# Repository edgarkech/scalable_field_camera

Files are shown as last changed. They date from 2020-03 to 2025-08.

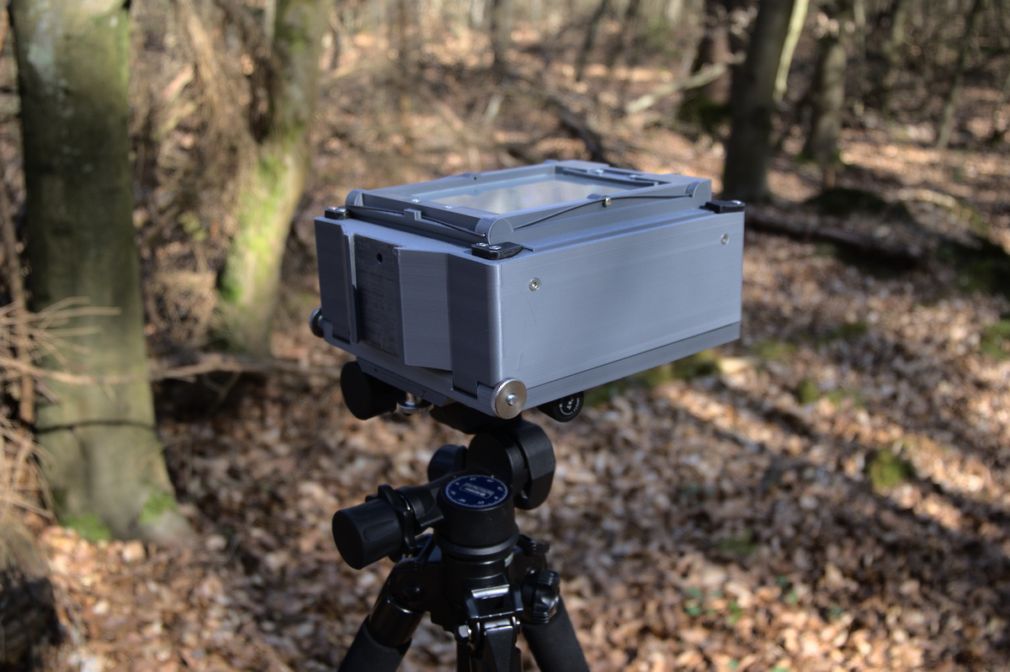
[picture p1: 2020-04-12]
pictures/version_1.0/XT203503.jpg

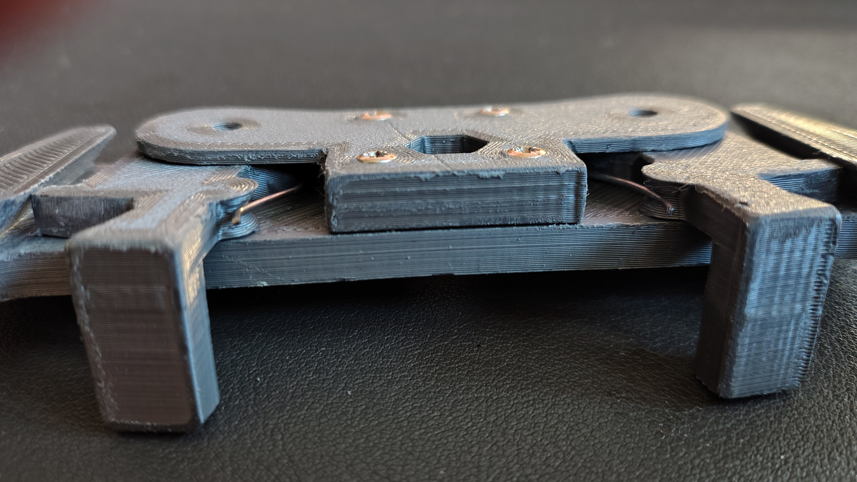
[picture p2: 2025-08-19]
pictures/version_1.0/IMG_20250819_194543976_HDR.jpg

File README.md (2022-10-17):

# Scalable large format field camera - 4&times;5 - 5&times;7 - 8&times;10

_This is my attempt to create a scalable large format field camera design._

## Project goals:
- of course a 3d printable and usable large format field camera in 4x5" format. The design should be scalable to 5x7" or even 8x10" by just changing a handful of variables.
- Learning OpenSCAD. Learning to use it efficiently. Learning to do good parametric development/design.
- Learning git/github and sharing my code with other people
- Checking out the limits of home 3D printing with a very limited set of available tools

## Some technical goals:
- the design is inspired by old and established field cameras like Horseman 45HD/FA or Linhof Technika. But it is also inspired by Intrepid and Standard Camera
- compact and lightweight. Projected weight for the 4x5 version with ground glass but without lens is below 1500g. The "overall package" should be lightweight, so don't expect me to design a rail and front standard for holding big and heavy lenses. for 4x5": usable with lenses from 90-300mm. Shorter or longer lenses are not targeted.
- a small standard lens should be able to stay on the camera when it is closed (e.g. Fujinon-WS 150/6.3 or Symmar 135/5.6, ...)
- rise of about 25-30mm with a normal lens
- fall of about 10mm with a normal lens
- front/back tilt of about 10 degrees
- left/right swing of about 10 degrees
- left/right shift optionally (probably not with first release)
- all movements on the front standard, no movements on the back
- easy switchable from landscape to portrait format
- tripod mount with Arca Swiss type mount
- all parts must be either 3D-printable or easily available.
- no special tools required besides a decent 3D printer and some common tools like little files, screwdrivers, sanding paper, cutter, scissors, ...
- no exotic third party parts/components
- form follows function
- KISS

## Early design decisions:
- completely 3D printed rail and front standard mechanism - lots of dovetails :-)
- for the initial 4x5 version I will use a bellows from standard cameras (https://www.standardcameras.com/product/replacement-bellows-v1-0/). For now it's relatively easy available, cheap and already mounted into a frame. For later versions, I will probably switch over to another source and add my own bellows mounting frame. For working with alternative bellows see the hints in the README file in folder STL_4x5, since you will have to build customized bellows frames using SCAD files.
- for the 5x7 version I will use a bellows from ebay-shop "ecbuyonline2008" which is orginally for a Linhof Technika 5x7 IV or V
- for the focusing rod I will use 6mm rods with 2mm pitch
- due to some printing related problems (first layer), I will avoid printing small holes directly onto the printing bed (smaller than 5mm). If holes are required, they will have a little offset on the Z-axis of 0.5mm. This will allow a "clean" first layer with really good adhesion, while the holes are "pre-drilled" for most of their depth

## First findings after finishing the first functional prototype
- PETG printing is somehow okay, but PLA is more rigid. Although I will do further tests with PETG, PLA stays the preferred material. This applies especially to the dovetails.
- completely printed front standard with (more than) acceptable stability is possible
- overall design seems to be a good starting point for further optimizations

## to do / next steps
- more real world testing (first tests successful)
- work around the current -7/+7 degrees tilt restriction (low priority)
- mechanism to lock the front lid when folding (done)
- foldable hood for the ground glass
- OpenSCAD code clean up and refinement (done)
- releasing the OpenSCAD code and make this project real open source  (done)
- scaling up to 5x7" (done)
- re-evaluate 4x5" bellows options (different source, design for configurable bellows frames is done) 
- using the built-in github wiki for documentation

# Update 2020-05-23
The 5x7 version is also finished. Although the 5x7" version is technically identical to the 4x5", there have been some changes to all SCAD files and I didn't test all of them again with 4x5. 
So if you are brave enough to work with the SCAD files to generate your own (4x5") STLs, please check them against my original 4x5 STLs.

# Update 2022-10-17
In the past there were some rumours or jokes about creating the 8x10" version, but nobody seemed to be brave enough to start the upscaling project. Or maybe the initially brave people gave up in despair... 
Until today. I had a conversation with Miguel Mesa (https://www.facebook.com/miguemesa), who now wants to start scaling up the design to 8x10" - which would be another milestone for my design. 
Although I am still pausing most of my photographic and 3d printing related activities, I am really curious how my design may evolve. And I want to encourage all watchers interested in a 8x10" version to participate and maybe even contribute to this next milestone.   

**Some very kind people asked me about the possibility to show their appreciation by donating to me.**

If you really felt somehow obliged to do so, then you should use https://paypal.me/EdgarKech :-) .
But I am also happy if you post pictures of your build to https://www.facebook.com/groups/3dprinting.and.analog.photography/

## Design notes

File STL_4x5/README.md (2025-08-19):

# 4&times;5 parts list

**We put our format specific STL files in here, so we get a complete set of STL files for building a camera in the specified format**

## Printed parts

All parts can be printed on any decent 3D printer with sufficient build volume 
- for 4x5" a smaller printer with about 190x190x100mm build volume is sufficient

Print settings vary slightly for the different parts - if not explicitly mentioned use
- 0.2mm layers or better
- 4 walls
- 4 bottom/top layers
- when printing with PETG, use at least 15-20% more infill as hinted below, below numbers are for PLA
The tolerances between the parts are quite tight, so you have to sand them. I recommend sanding the dovetail parts with 400 wet sanding paper. 

### printed parts list
- body, infill 30%, support for overhang angles over 60 degrees, support touching the build plate
- front lid, infill 30%, no supports
- front lid dovetail, infill 30%, no supports
- focusing block, infill 100%, no supports
- focusing wheel, infill 100%, no supports
- back plate, 30% infill, no supports
- locking rails (1x original, 1x mirrored), infill 100%, no supports
- locking levers (1x original, 1x mirrored), infill 100%, no supports
- rails, min 40% infill, support for overhang angles over 60 degrees
- slider, min 50% infill, no supports
- front standard, min 50% infill, support for overhang angles over 80 degrees, support everywhere, do not print the standard in its upright position, but layed down to its back side
- front standard tilt plates (2x) min 50% infill, support for overhang angles over 80 degrees, support touching the build plate
- pulling lever plate, 100% infill, no supports
- pulling levers (1x original, 1x mirrored), 100% infill, no supports
- lensboard carrier, min 40% infill, support for overhang angles over 60 degrees, support touching the build plate
- lensboard lower clamp, 100% infill, no supports
- lensboard upper clamp, 100% infill, no supports
- ground glass frame, infill 30%, no supports,
- ground glass clamps, 100% infill, no supports
- tripod plate, min 50% infill, no supports
- only needed when not using a bellows from standard cameras: bellows front frame, min 50% infill, no supports
- only needed when not using a bellows from standard cameras: bellows back frame, min 50% infill, no supports

### non-printed parts
- bellows, for 4x5" order the bellows from standardcameras.com or from eBay or from aliexpress (e.g. from ecbuyonline2008 aka eTone)
- focusing rod: T6, 2 or 4mm lead, 160mm length
- T6 nut (brass) 
- flange coupler 6mm
- M5 threaded rod, 200mm
- M5x20 screw (1x)
- M5x10 knurled nuts (3x)
- M5x10...12 screws with knurled heads (2x)
- M5x12...16 screws with knurled heads (2x)
- M5 press-in nuts (5x)
- countersunk screws 3x12 (about 35x)
- countersunk screws 2x10 (about 10x)
- ground glass 127x101mm
- about 600mm of 1.25mm spring steel wire for the ground glass frame
- about 100mm of 0.75mm spring steel wire for the pulling lever mechanism

## some hints & sources:
### bellows
History has shown that standardcameras is sometimes out of stock for the bellows.
- Alternative 1: build your own bellows (sorry, no howto from me, but there are lots of excellent sources!)
- Alternative 2: Find a replacement bellows for another field camera (e.g. Linhof Technika 4x5, Toyo 45A, Horseman, HD/HF/FA 45, ...). 

Make sure to get squared bellows with a front measurement of something between 88 and 98mm (default is 94mm) and a back measurement of something between 141 and 153mm (default is 144mm).

You have to create your own STLs for the bellow frames from the according SCAD files. In the config_4x5.scad file find the variables "vBellowsFrontInner_l" and "vBellowsBackInner_l" and change them to the measurements of your bellows - don't change anything else unless you have a really good reason for it. Let OpenSCAD render your SCAD files and export to STL.

### bellows frames (in case you are not using bellows from standard cameras):
The bellows frames consist of two individual parts (inner and outer frame), but I modeled them as one piece for easier modeling and printing. 
They are just "linked" together via the bottom 0.1mm (for easier printing). Just use a knife to split inner and outer frame and clean up the edges.

### dove tails:
the fit of the various dove tails may be very tight in the beginning. So I'd recommend pre-assembling the dovetails and trying to move the parts. If it is too tight, use fine sandpaper until there is only very little friction. It shouldn't get wobbly.

### front standart:
don't try to print the front standart in its upright position. Lay it down ot its back side and make sure to allow support everywhere.
Assembling:
- Make sure the dove tails of slider and front standard aren't too tight (see section "dove tails")
- put slider and front standard together before assembling the pulling lever mechanism.

### pulling levers assembly
- pulling levers and pulling lever plate: put them together and rotate the pulling levers on their axis until there is no noticable friction. If the holes in the levers are too small, use a 8mm drill bit (just by hand) to widen it.
- pulling lever plate: make sure that little horizontal hole is open (if not, you could use either a 1.5mm drill bit or a hot wire to push it open). This is where you put the spring wire through and bend it on both sides almost to a right angle (let's say 110 degrees). Don't cut the spring steel wire too short before final assembly.
- see the pictures in the pictures/version_1.0 folder https://github.com/edgarkech/scalable_field_camera/tree/master/pictures/version_1.0 

### assembling the front standard
- start with slider and front standard, otherwise it may be difficult to get the front standard onto the slider with the pulling levers already assembled.
- pre-assemble pulling lever plate, spring wire and pulling levers
- put the pulling assembly to the bottom of the slider and screw it to the slider.
- see again the pictures in the pictures/version_1.0 folder https://github.com/edgarkech/scalable_field_camera/tree/master/pictures/version_1.0 

### focusing rod:
Find "T6 lead screw" with fitting brass nuts on aliexpress, ebay or your preferred source, similar to this offer: https://www.aliexpress.com/item/32507277503.html. 
Take either 2mm or 4mm lead with 200mm length. 
Cut it to about 160 to 165mm. 
Press the nut into the 10mm hole of the rail lever. 
Secure it with one small screw and file down everything hanging over
- see again the pictures in the pictures/version_1.0 folder https://github.com/edgarkech/scalable_field_camera/tree/master/pictures/version_1.0 

### focusing wheel:
Find "6mm flange coupler" on aliexpress, ebay or your preferred source, similar to this offer: https://www.aliexpress.com/item/4000208248034.html.
Press it into the Focusing wheel and align the side holes with the threads, so you can screw in the tiny screws.

### threaded inserts:
Find "M5 threaded insert" on aliexpress, ebay or your preferred source. I am using M5x6x7 brass insert similar to this: https://www.ebay.com/itm/M5x-5-16mm-Injection-Molding-Nut-Brass-Knurled-Thread-Inserts-Nuts/332250787457. 
Make them hot and press them into the according holes using a M5 threaded rod or a longer screw.

### knobs:
All knobs are quite standard M5 screws or nuts. 
3x nut M5, one for swing and two for the lid. 
2x M5x16 for tilt, 2x M5x12 for shift (the flat ones). 
Also one M5x12 for the tripod plate. 
I prefer stainless steel but anything else with similar size will do.

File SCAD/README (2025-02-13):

Some hints about the scripting and according conventions in here - as my OpenSCAD scripting is learning by doing, some constructs may look crude or even violate best practice.
I am using some rules and conventions to make my scripting as consistent, readable and maintainable as possible.

General logic for getting this design parametric:
- baseconfig.scad holds very generic configuration values which are independent of the targeted camera format. But it also includes the format specific config file.
- config_4x5.scad/config_5x7.scad/config_8x10.scad are the format specific configuration files. Here we set some basic, format specific variables from which we can derive lots of measures for our design
- all other scad files are including the baseconfig.scad file to get all basic and format dependent variables for deriving the specific measures

Naming conventions
- all Variables are prefixed with "v"
- all Variables are (somehow) speaking, eg. vFrontLidOuter_l
- suffix _l is typically a measure in x direction
- suffix _w is typically a measure in y direction
- suffix _h is typically a measure in z direction
- suffix _d/_d1/_d2 are typically a diameter variables
- suffix _r/_r1/_r2 are typically radius variables 
- suffix _offsetX/_offsetY/_offsetZ are offset variables to be used in translate() statements
- every basic element has its own set of l/w/h/d/r variables
- every element will have its own set of offset variables

Other conventions
- mathematic operations are done within the variables. 
- most parts are symetric, so we center them on the X axis
- try to keep the scripting readable

Creating STLs for bellows frames:
1. go to https://github.com/edgarkech/scalable_field_camera/releases/tag/v1.02 and download the complete source code zip-file. (skip, if your already downloaded+extracted the sources)
2. extract the zip file. you should find a subfolder "SCAD" (skip, if your already downloaded+extracted the sources)
3. go to the SCAD folder and open the "baseconfig.scad" file
4. make sure the correct format-specific include line is active (not startingwith "//") - there are three lines, one for 4x5, one for 5x7, one for 8x10; the two lines NOT for your targeted format should be commented out, e.g. starting with "//"
5. if necessary make changes by commenting/uncommenting and save the file
6. open the relevant format-specific config file (probably config_4x5.scad)
7. take the real measurements from your bellows. On the front you should have a measurement somewhere between 88 and 98mm (default is 94), on the back it should be between 141 and 153mm (default is 144mm)
8. find the variables "vBellowsFrontInner_l" and "vBellowsBackInner_l" and change them to the measurements of your bellows - don't change anything else unless you have a really good reason for it. 
9. save the file.
10. open the bellows_front_frame.scad file, let OpenSCAD render it and export to STL.
11. open the bellows_back_frame.scad file, let OpenSCAD render it and export to STL.
12. print your STL files

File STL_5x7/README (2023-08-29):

We put our format specific STL files in here, so we get a complete set of STL files for building a camera in the specified format

Printed parts

All parts can be printed on any decent 3D printer with sufficient build volume 
- for 5x7" a build volume of at least 235x235x100mm is required

Print settings vary slightly for the different parts - if not explicitly mentioned use
- 0.2mm layers or better
- 4 walls
- 4 bottom/top layers
- when printing with PETG, use at least 15-20% more infill as hinted below, below numbers are for PLA
The tolerances between the parts are quite tight, so you have to sand them. I recommend sanding the dovetail parts with 400 wet sanding paper. 

printed parts list
- body, infill 30%, support for overhang angles over 60 degrees, support touching the build plate
- front lid, infill 30%, no supports
- front lid dovetail, infill 30%, no supports
- focusing block, infill 100%, no supports
- focusing wheel, infill 100%, no supports
- back plate, 30% infill, no supports
- locking rails (1x original, 1x mirrored), infill 100%, no supports
- locking levers (1x original, 1x mirrored), infill 100%, no supports
- rails, min 40% infill, support for overhang angles over 60 degrees
- slider, min 50% infill, no supports
- front standard, min 50% infill, support for overhang angles over 80 degrees, support everywhere, do not print the standard in its upright position, but layed down to its back side
- front standard tilt plates (2x) min 50% infill, support for overhang angles over 80 degrees, support touching the build plate
- pulling lever plate, 100% infill, no supports
- pulling levers (1x original, 1x mirrored), 100% infill, no supports
- lensboard carrier, min 40% infill, support for overhang angles over 60 degrees, support touching the build plate
- lensboard lower clamp, 100% infill, no supports
- lensboard upper clamp, 100% infill, no supports
- ground glass frame, infill 30%, no supports,
- ground glass clamps, 100% infill, no supports
- tripod plate, min 50% infill, no supports
- bellows front frame, min 50% infill, no supports
- bellows back frame, min 50% infill, no supports

non-printed parts
- bellows, order the bellows from from eBay or aliexpress
- focusing rod: T6, 2 or 4mm lead, 200mm length
- T6 nut (brass) 
- flange coupler 6mm
- M5 threaded rod, 250mm
- M5x20 screw (1x)
- M5 knurled nuts (3x)
- M5x10 screws with knurled heads (2x)
- M5x12 screws with knurled heads (2x)
- M5 press-in nuts (4x)
- countersunk screws 3x12 (30x)
- countersunk screws 2x10 (6x)
- ground glass 5x7"
- about 700mm of 1.25mm spring steel wire for the ground glass frame
- about 100mm of 0.75mm spring steel wire for the pulling lever mechanism

some hints & sources:
focusing rod:
Find "T6 lead screw" with fitting brass nuts on aliexpress, ebay or your preferred source, similar to this offer: https://www.aliexpress.com/item/32507277503.html. 
Take either 2mm or 4mm lead with 200mm length. 
Cut it down to fit into the lid. 
Press the nut into the 10mm hole of the rail lever. 
Secure it with one small screw and file down everything hanging over

bellows frames:
The bellows frames consist of two individual parts (inner and outer frame), but I modeled them as one piece for easier modeling and printing. 
They are just "linked" together via the bottom 0.1mm (for easier printing). Just use a knife to split inner and outer frame and clean up the edges.

front standart:
don't try to print the front standart in its upright position. Lay it down ot its back side and make sure to allow support everywhere.

focusing wheel:
Find "6mm flange coupler" on aliexpress, ebay or your preferred source, similar to this offer: https://www.aliexpress.com/item/4000208248034.html.
Press it into the Focusing wheel and align the side holes with the threads, so you can screw in the tiny screws.

threaded inserts:
Find "M5 threaded insert" on aliexpress, ebay or your preferred source. I am using M5x6x7 brass insert similar to this: https://www.ebay.com/itm/M5x-5-16mm-Injection-Molding-Nut-Brass-Knurled-Thread-Inserts-Nuts/332250787457. 
Make them hot and press them into the according holes using a M5 threaded rod or a longer screw.

knobs:
All knobs are quite standard M5 screws or nuts. 
3x nut M5, one for swing and two for the lid. 
2x M5x16 for tilt, 2x M5x12 for shift (the flat ones). 
Also one M5x12 for the tripod plate. 
I prefer stainless steel but anything else with similar size will do.

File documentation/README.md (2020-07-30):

# Documentation

Here's an attempt at guiding the assembly and build process of the Scalable Field Camera.

For now, it only contains an exploded view and assembly mockups in `assembly` but we aim to create a step-by-step guide soon :)

**The assembly images are based on the 4&times;5 camera files**

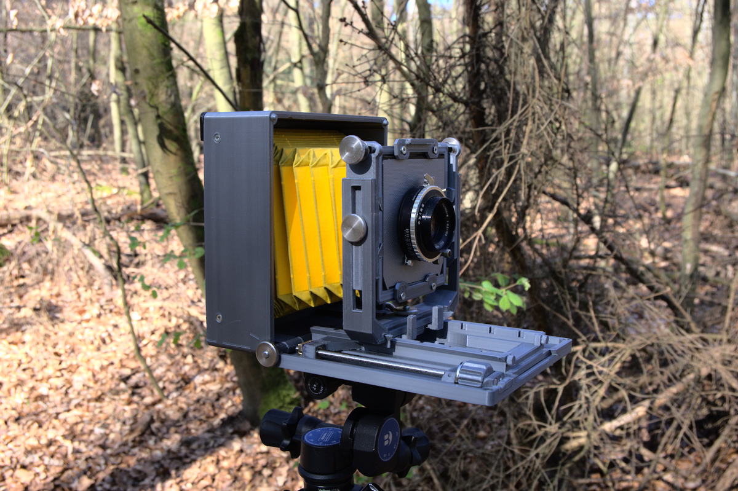
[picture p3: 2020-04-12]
pictures/version_1.0/XT203507.jpg

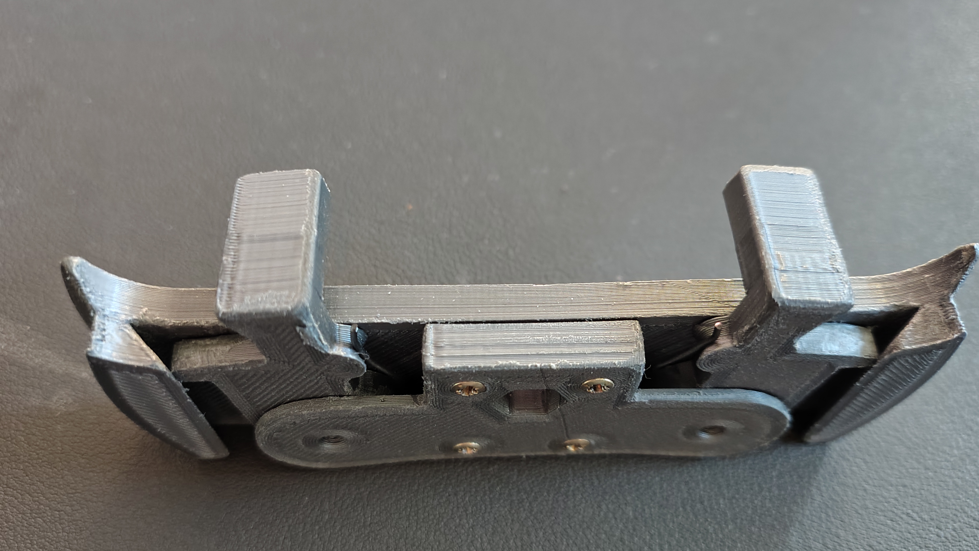
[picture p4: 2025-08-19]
pictures/version_1.0/IMG_20250819_194521298_HDR.jpg

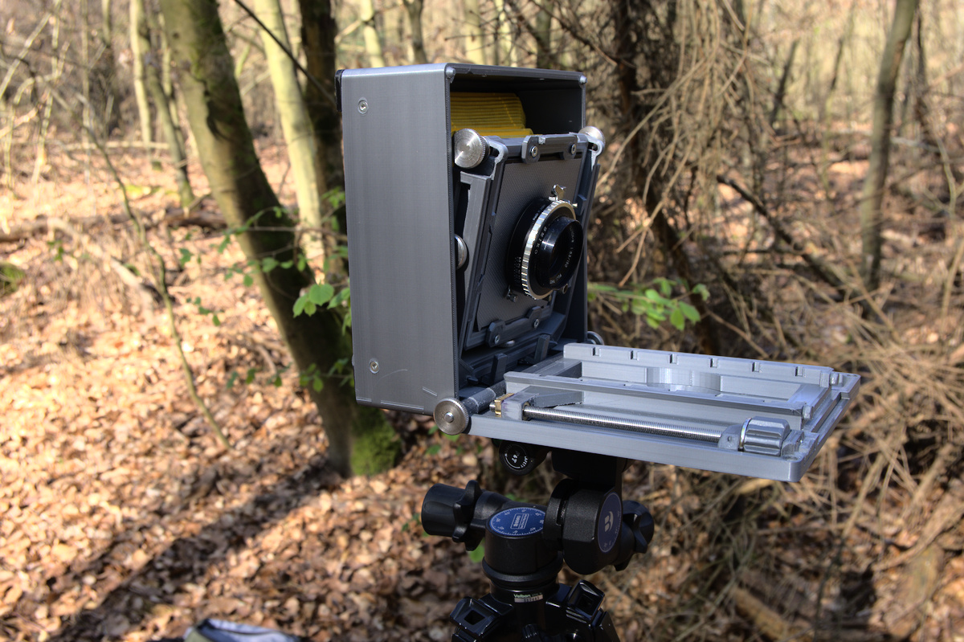
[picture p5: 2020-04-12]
pictures/version_1.0/XT203506.jpg

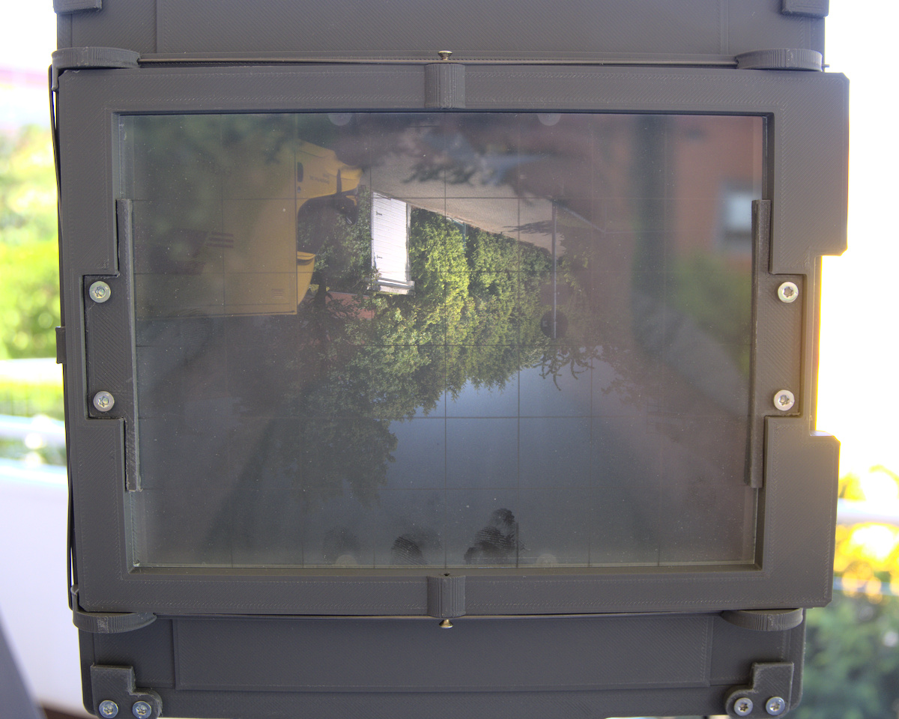
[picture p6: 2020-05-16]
pictures/XT203548.jpg

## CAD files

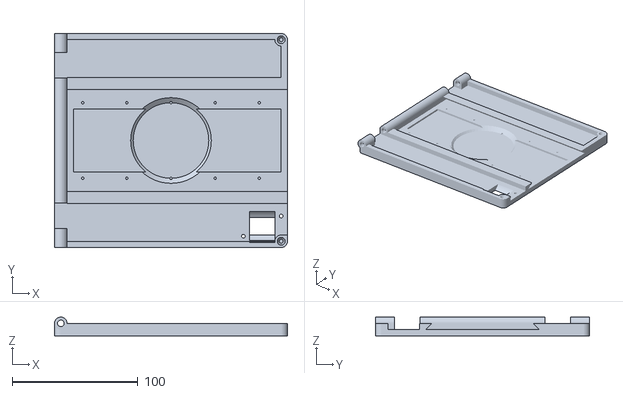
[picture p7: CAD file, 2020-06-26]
STL_4x5/front_lid.stl
185.0 x 170.0 x 15.0

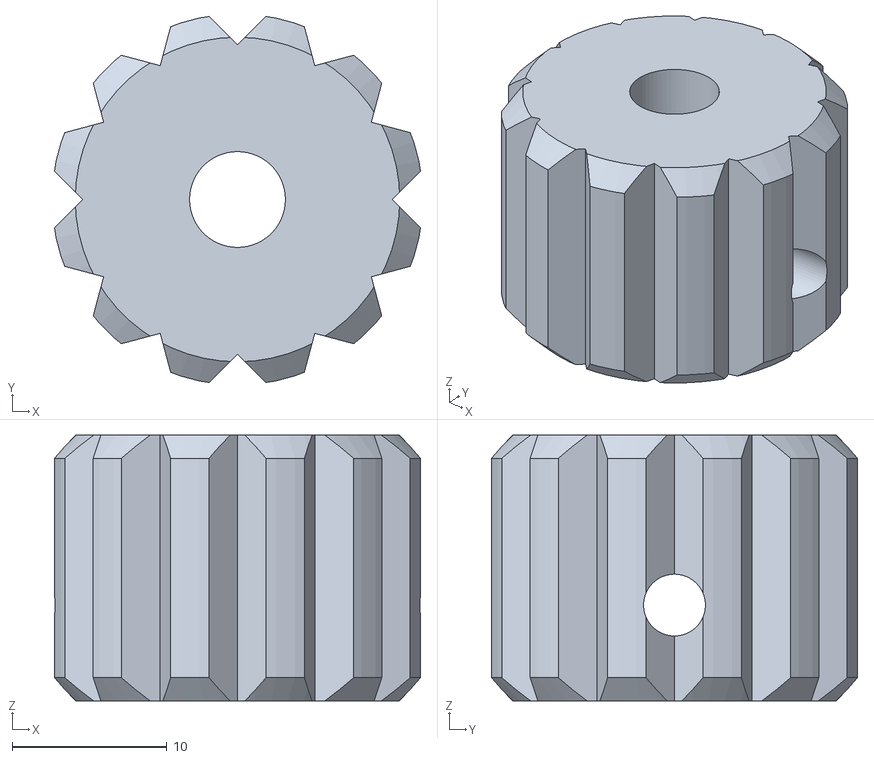
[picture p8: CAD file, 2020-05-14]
STL_5x7/focus_wheel.stl
23.7 x 23.7 x 17.2

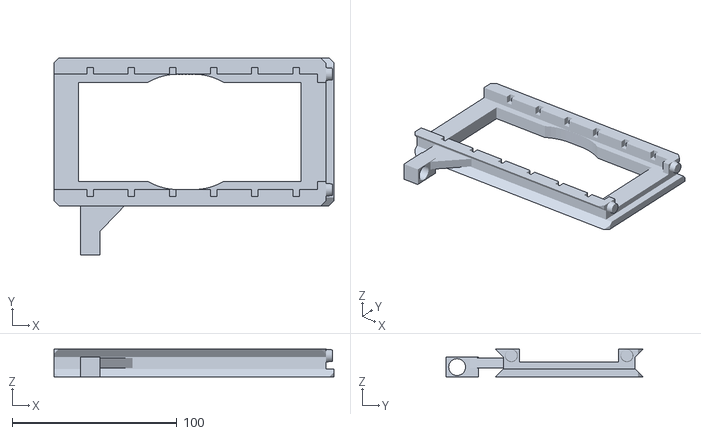
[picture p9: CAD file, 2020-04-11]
STL_4x5/rails.stl
170.0 x 119.7 x 17.0

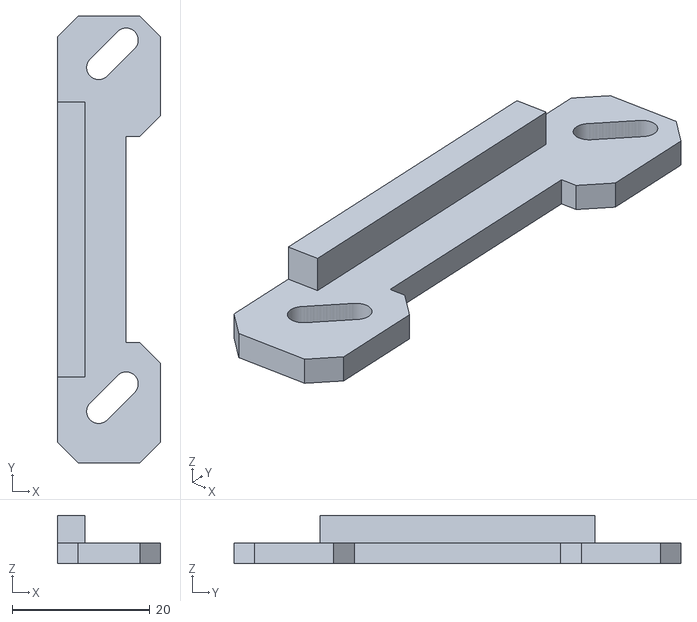
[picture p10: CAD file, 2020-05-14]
STL_5x7/lensboard_upper_clamp.stl
15.0 x 65.0 x 7.00

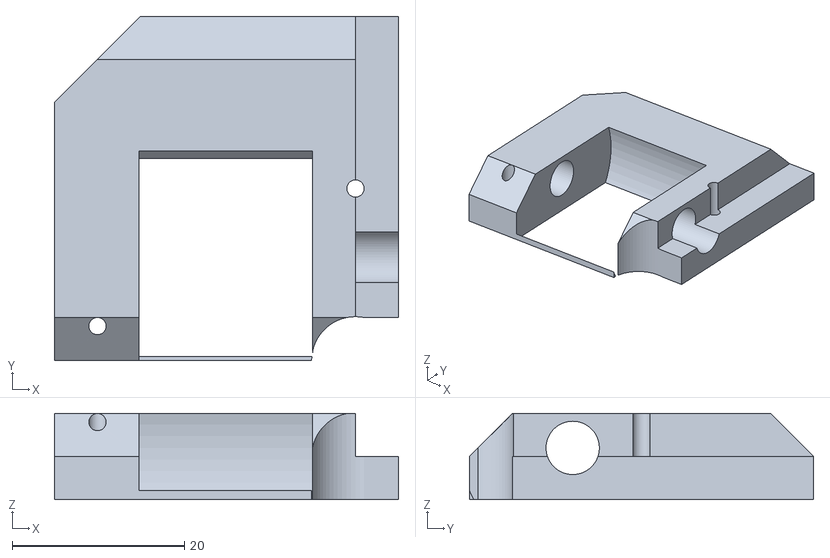
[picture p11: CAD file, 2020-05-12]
STL_5x7/focusing_block.stl
40.0 x 40.0 x 10.0

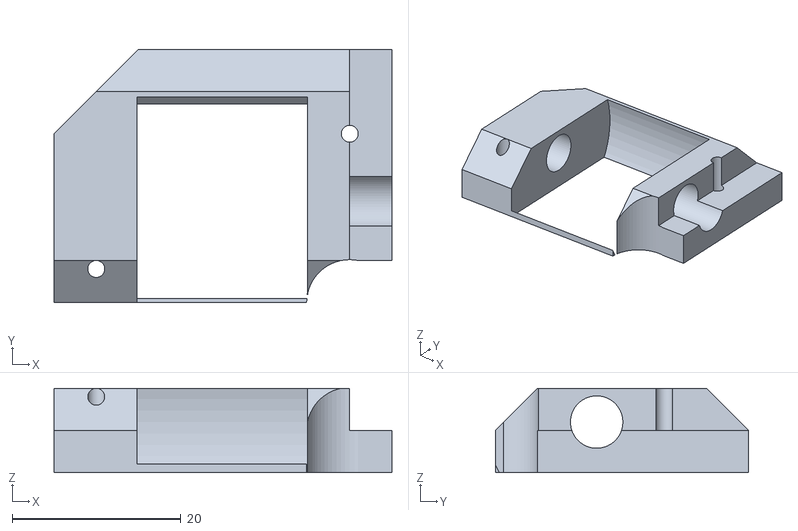
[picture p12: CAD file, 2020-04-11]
STL_4x5/focusing_block.stl
40.0 x 30.0 x 10.0

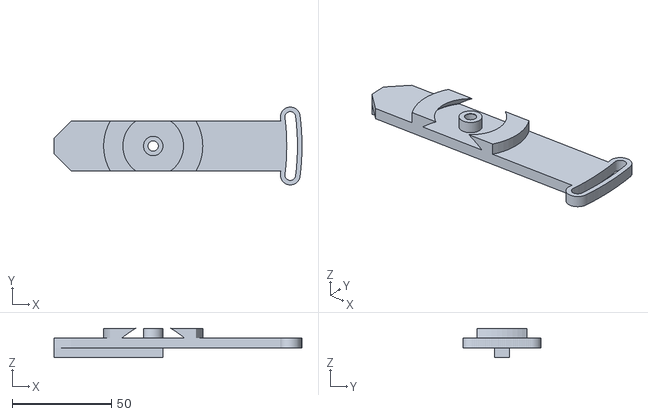
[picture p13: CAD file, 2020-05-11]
STL_5x7/front_standard_tilt_plate.stl
125.0 x 39.2 x 14.8

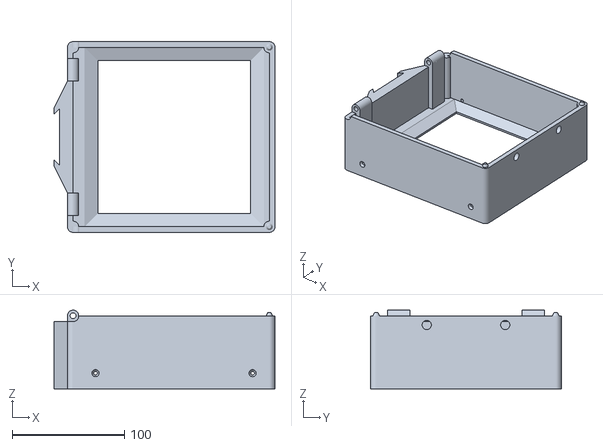
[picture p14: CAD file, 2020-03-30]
STL_4x5/body.stl
197.0 x 170.0 x 70.2

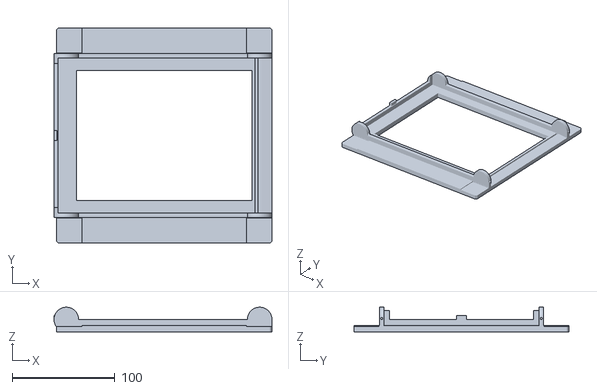
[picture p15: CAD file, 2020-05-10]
STL_5x7/back_plate.stl
212.1 x 209.6 x 24.0

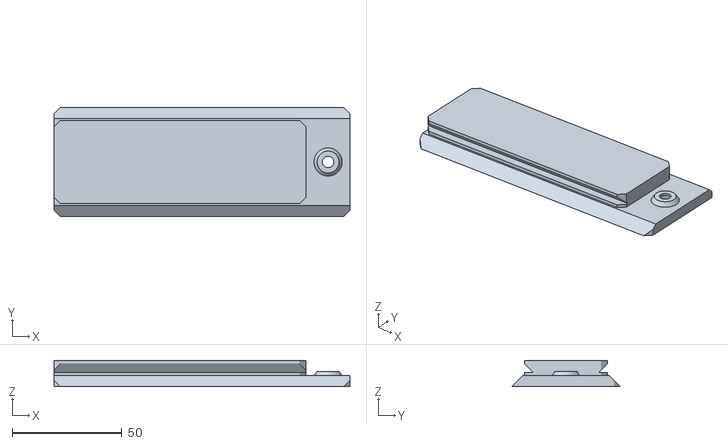
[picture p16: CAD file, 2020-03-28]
STL_4x5/tripod_plate.stl
135.0 x 49.8 x 12.0

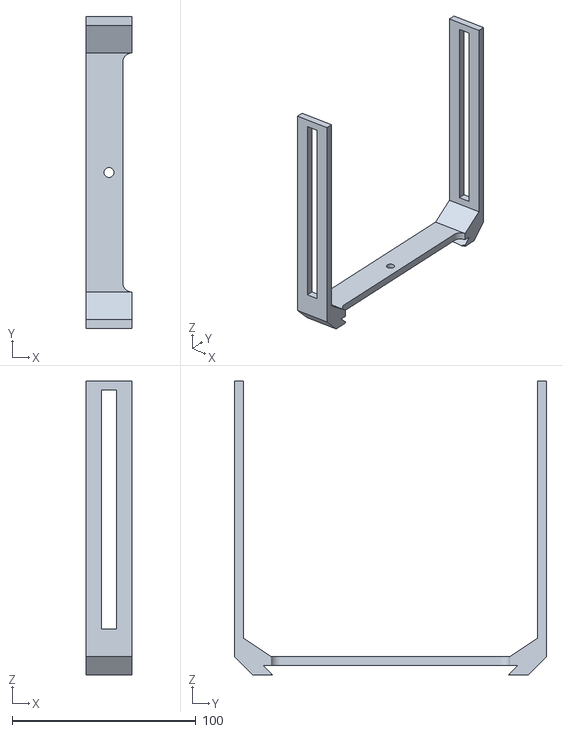
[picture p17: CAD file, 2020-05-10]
STL_5x7/front_standard.stl
25.0 x 170.0 x 160.0

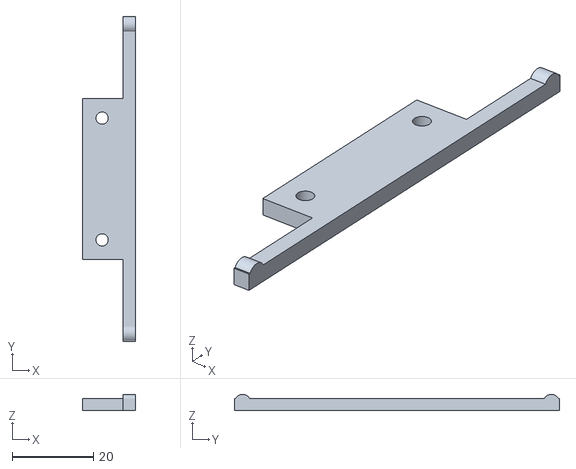
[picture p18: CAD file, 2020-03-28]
STL_4x5/ground_glass_clamp.stl
13.0 x 80.0 x 4.00

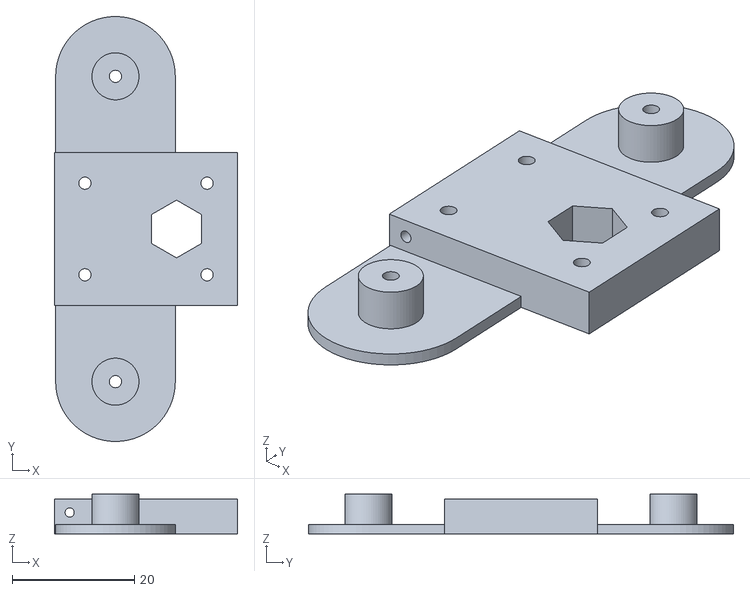
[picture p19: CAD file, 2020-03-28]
STL_4x5/pulling_lever_plate.stl
30.0 x 69.6 x 6.50

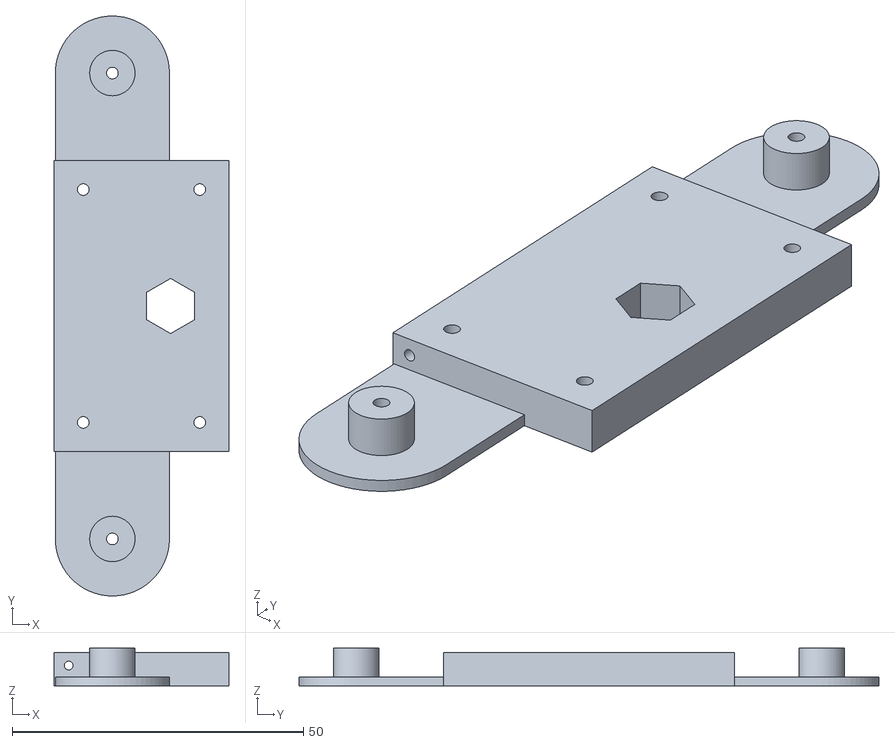
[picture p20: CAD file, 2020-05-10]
STL_5x7/pulling_lever_plate.stl
30.0 x 99.6 x 6.50

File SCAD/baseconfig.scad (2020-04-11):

/*
Here we define some variables which are independent from the camera format
*/


// some generic variables
$fn = 60; // we are using 60 fragments for cylinders and similar objects

// we are including a format specific configuration sheet - but make sure to include only one!

include <config_4x5.scad>;
// include <config_5x7.scad>;
// include <config_8x10.scad>;

// Arca Swiss tripod plate
// caution: some Arca Swiss compatible tripod heads may have slight variations
// vArca_length = xx; // the length is irrelevant here
vArca_width = 38;
vArca_height = 7;
vArcaBase_cutout = 4;
vArcaBase_height = 1.5;

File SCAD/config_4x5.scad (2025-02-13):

/*
This is the base configuration file for the 4x5" format
# we are not using the exact ANSI measures, but slightly rounded measures for slight simplification
*/

// general tolerance
vTolerance = 0.2;

// sheet film and cassette measurements (roughly based on the ANSI measurements)
vFilmSheet_l = 127;
vFilmSheet_w = 102;
vCassette_l = 160; // A min
vCassette_w = 121; // B max
vCassette_h = 13.2; // C max
vLightTrap_l = 2; // M2
vLightTrap_w = vCassette_w;
vLightTrap_h = 1.5; // M1
vLightTrap_offsetX = 141; // G max
vFilmWindow_l = 121;
vFilmWindow_w = 101;
vFilmWindow_offsetX = 16;
vGroundGlass_offsetZ = 5;

// Graflok
vGraflok_h = 6; // this is not the official measurement, just measured from a camera 

// lens board measures (we are using Wista/Technika-style lensboards)
vLensboard_l = 100;
vLensboard_w = 97;
vLensboard_h = 2;
vLensboard_offsetX = -(vLensboard_l+3)/2; // caution: we have an asymetric offset!
vLensboard_offsetY = -vLensboard_w/2;
vLensboardHole_d = 85;
vLensboardLighttrap_d = 89;
vLensboardLighttrap_h = 1+vTolerance;

// bellows frame measures - the bellows frame design is derived from standardcameras.com
// back frame
vBellowsBackInner_l = 144; //???? check and replace with the measurement from your bellows!
vBellowsBackInner_w = vBellowsBackInner_l;
vBellowsBackOuter_l = vBellowsBackInner_l+1;
vBellowsBackOuter_w = vBellowsBackOuter_l;

vBellowsBackFrameOuter_l = 159;
vBellowsBackFrameOuter_w = vBellowsBackFrameOuter_l;
vBellowsBackFrameOuter_h = 7;
vBellowsBackFrameInner_l = 135;
vBellowsBackFrameInner_w = vBellowsBackFrameInner_l;
vBellowsBackFrameInner_h = 5;

vBellowsBackLightTrapOuter_l = vBellowsBackFrameInner_l+2*2;
vBellowsBackLightTrapOuter_w = vBellowsBackLightTrapOuter_l;
vBellowsBackLightTrap_h = 3;

vBellowsBackFrameScrewHole_d = 2;
vBellowsBackFrameScrewHole_h = 10;
vBellowsBackFrameScrewHole_offsetXY = 70;
vBellowsBackFrameScrewHole_offsetZ = vBellowsBackFrameOuter_h/2;

// front frame
vBellowsFrontInner_l = 94; //???? check and replace with the measurement from your bellows!
vBellowsFrontInner_w = vBellowsFrontInner_l;
vBellowsFrontOuter_l = vBellowsFrontInner_l+1;
vBellowsFrontOuter_w = vBellowsFrontOuter_l;

vBellowsFrontFrameOuter_l = 104;
vBellowsFrontFrameOuter_w = vBellowsFrontFrameOuter_l;
vBellowsFrontFrameOuter_h = 7;
vBellowsFrontFrameInner_l = 82;
vBellowsFrontFrameInner_w = vBellowsFrontFrameInner_l;
vBellowsFrontFrameInner_h = 5;

vBellowsFrontLightTrapOuter_l = vBellowsFrontFrameInner_l+2*2;
vBellowsFrontLightTrapOuter_w = vBellowsFrontLightTrapOuter_l;
vBellowsFrontLightTrap_h = 0;

vBellowsFrontFrameScrewHole_d = 2;
vBellowsFrontFrameScrewHole_h = 10;
vBellowsFrontFrameScrewHole_offsetXY = 40;
vBellowsFrontFrameScrewHole_offsetZ = vBellowsFrontFrameOuter_h/2;

// body dimensions
vWall_strength = 5;
vBodyOuter_l = 185; // make sure this is at least 4*vWall_strength larger than vBellowsBackFrameOuter_l!
vBodyOuter_w = 170; // make sure this is at least 2*vWall_strength larger than vBellowsBackFrameOuter_l!
vBodyOuter_h = 65;
vBodyEdge_r = vWall_strength;

// we will center our model on the Y axis and on the center of the bellows frame
// at least for the 4x5 version, we have to do an asymetric offset of 2.5mm on the X-axis 
vAsymOffsetX = -2.5;  

// back plate
vBackPlateLength = 160; // we will probably use about the same size as the bellows back frame
vBackPlateStrength = vWall_strength;

// hinges for front lid
vHingeInnerDistance = 100;
vHingeBaseWidth = 20;
vHingeHole = 5;

// lid lock measures
vLidLockBase_d = 8;
vLidLockHole_distance = 70;

// rail dimensions
vLowerRail_w = 90;
vUpperRail_w = vLowerRail_w;

// cutout for stop indents
vStopIndent_l = 4;
vStopIndent_h = 5;
vStopIndentDistance = 25; // shorter than 25 is not necessary
vStopIndent_offsetX = 20; // don't go shorter than 20 if you intend to use a 90mm lens!

// for all dovetails we use a base width of 5mm and a base height of 5mm
// we are applying tolerances to the inner AND outer part of a dovetail, in width and height
vDoveTail_w = 5;
vDoveTail_h = 5;
vDoveTail_tolerance = 0.2;

// front standard carrier / slider
// width is depending on vUpperRail_w
vSliderBase_w = vUpperRail_w + (4*vDoveTail_w);
vSliderBase_l = 40; // make sure to have enough space in the body.


// lever plate 
vLeverPlateBase_w = vUpperRail_w - (8*vDoveTail_w);
vLeverPlateBlock_w = 25;
vLeverPlateBlock_l = vSliderBase_l-(2*vDoveTail_w);

vFrontStandard_h = 130;
vFrontStandardSlot_h = vFrontStandard_h - 30;

// lensboard carrier
vFrontPlate_length = vSliderBase_w+6; // vSliderBase_w is a bit too tight for 4x5", so there we will add 5mm, for 5x7 vSliderBase_w is OK to get a squared lensboard carrier
vFrontPlate_width = vSliderBase_w; //vFrontPlate_length;
vFrontPlate_height = 16;
vEdgeCutCylinder = floor(sqrt(2*pow(vFrontPlate_width,2)))-5;

vTiltDovetailBase_d1 = 30;
vTiltDovetailBase_d2 = vTiltDovetailBase_d1+(2*vDoveTail_w);
vTiltDovetailBaseBlock_d = vTiltDovetailBase_d1+(4*vDoveTail_w);

vTiltDovetail_d1 = vTiltDovetailBase_d1-vTolerance;
vTiltDovetail_d2 = vTiltDovetailBase_d2-vTolerance;
vTiltDovetail_h = vDoveTail_w-vTolerance;

vTiltDovetailCutout_d1 = vTiltDovetailBase_d2+vTolerance;
vTiltDovetailCutout_d2 = vTiltDovetailBase_d1+vTolerance;

vAxisHole_d = 10+vTolerance;
vAxisHole_h = vDoveTail_w+vTolerance;

vTiltLockBolt_d = 12;
vTiltLockBolt_h = 14;
vTiltLockBoltHole_d = 8;
vTiltLockBoltHole_h = vTiltLockBolt_h;

vTiltHeight = 50;
vTiltRadius = vFrontPlate_length/2;
vTiltAngleMinus = -7;
vTiltAnglePlus = 7;
vTiltAxis_d = 10-vTolerance;

// focusing rod
vFocusingRod_d = 6;
vFocusingKnob_d = 25;
vFocusingKnob_h = 20;

// stabilizer measures (just the outer measures of our stabilizer block, not the tripod slider)
vStabilizerBase_l = 140;
vStabilizerBase_w = 100;  
vStabilizerBase_h = 7;
vStabilizerDovetailBase_w = 50;
// screw holes for the stabilizer
vLidHoleCount_x = 5;
vLidHoleDist_x = 35;
vLidHoleCount_y = 2;
vLidHoleDist_y = 60;


// screw diameters, length is individually set
vScrew1Hole_d = 3;
vScrew1ThreadHole_d = 2.2;
vScrew2Hole_d = 2;
vScrew2ThreadHole_d = 1.4;


 

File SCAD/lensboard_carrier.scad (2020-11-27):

// loading the base configuration
include <baseconfig.scad>;

// some modules such as hex, countersunk screws, roof, wedge are available in a module file
use <modules.scad>;


// some variables
// $fn = 120; // we are using 120 fragments for cylinders and similar objects

vFrontPlate_offsetX = -vFrontPlate_length/2;
vFrontPlate_offsetY = -vFrontPlate_width/2;
vFrontPlate_offsetZ = 0;

vTiltDovetail_offsetX = 0;
vTiltDovetail_offsetY = vFrontPlate_width/2;
vTiltDovetail_offsetZ = vFrontPlate_height/2;

vAxisHole_offsetX = 0;
vAxisHole_offsetY = vFrontPlate_width/2;
vAxisHole_offsetZ = vFrontPlate_height/2;

vTiltLockBolt_offsetX = -vFrontPlate_length/2;
vTiltLockBolt_offsetY = -(vFrontPlate_width+(2*vDoveTail_w))/2;
vTiltLockBolt_offsetZ = vFrontPlate_height/2;

vBellowsCutoutLower_length = vBellowsFrontFrameOuter_l+(2*vTolerance);
vBellowsCutoutLower_width = vBellowsCutoutLower_length;
vBellowsCutoutLower_height = vBellowsFrontFrameOuter_h;
vBellowsCutoutLower_d = sqrt(2*pow(vBellowsCutoutLower_length,2));
vBellowsCutoutUpper_length = vBellowsFrontFrameInner_l+(2*vTolerance);
vBellowsCutoutUpper_width = vBellowsCutoutUpper_length;
vBellowsCutoutUpper_d = sqrt(2*pow(vBellowsCutoutUpper_length,2));
vBellowsCutoutUpper_height = vBellowsFrontFrameInner_h;
vBellowsCutoutLower_offsetX = -vBellowsCutoutLower_length/2;
vBellowsCutoutLower_offsetY = -vBellowsCutoutLower_width/2;
vBellowsCutoutLower_offsetZ = 0;
// for the upper cutout we are using a cylinder, so we have to center it
vBellowsCutoutUpper_offsetX = 0;
vBellowsCutoutUpper_offsetY = 0;
vBellowsCutoutUpper_offsetZ = vBellowsCutoutLower_height;

vLensBoardCutout_length = vLensboard_l;
vLensBoardCutout_width = vLensboard_w;
vLensBoardCutout_height = vLensboard_h+vTolerance;
vLensBoardCutout_offsetX = -(vLensBoardCutout_width/2)-3;
vLensBoardCutout_offsetY = -vLensBoardCutout_width/2;
vLensBoardCutout_offsetZ = vFrontPlate_height-vLensBoardCutout_height;

vLensBoardHole_d = vLensboardHole_d;
vLensBoardHole_h = vFrontPlate_height;
vLensBoardCircle_d = vLensboardLighttrap_d;
vLensBoardCircle_h = vLensboardLighttrap_h;
vLensBoardCircle_offsetZ = vFrontPlate_height-vLensBoardCutout_height-vLensBoardCircle_h;

vBellowsScrewHole_d = 3;
vBellowsScrewHole_h = vFrontPlate_length;
vBellowsScrewSinking_d1 = 6;
vBellowsScrewSinking_h = vBellowsScrewSinking_d1/2;
vBellowsScrewHole_offsetX = -vFrontPlate_length/2;
vBellowsScrewHole_offsetY = vBellowsCutoutUpper_length/2;
vBellowsScrewHole_offsetZ = vBellowsCutoutLower_height/2;

vClampHole_d = 2;
vClampHole_h = 8;
vClampHole_offsetX1 = vLensBoardCutout_offsetX-4;
vClampHole_offsetX2 = vLensBoardCutout_offsetX+vLensboard_l+4;
vClampHole_offsetY = 25;
vClampHole_offsetZ = vFrontPlate_height-vClampHole_h;

vSwingScrewCutout_l = 5;
vSwingScrewCutout_w = 80;
vSwingScrewCutout_h = vFrontPlate_height;
vSwingScrewCutout_offsetX = vFrontPlate_length/2 - vSwingScrewCutout_l;
vSwingScrewCutout_offsetY = -vSwingScrewCutout_w/2;
vSwingScrewCutout_offsetZ = 0;

difference(){

union(){
    
    intersection(){
        // base cube
        translate([vFrontPlate_offsetX, vFrontPlate_offsetY, vFrontPlate_offsetZ])
            cube([vFrontPlate_length, vFrontPlate_width, vFrontPlate_height]);
        // rounding the edges
        cylinder(d=vEdgeCutCylinder, h=vFrontPlate_height);
    };
    
    
    translate([vTiltDovetail_offsetX, vTiltDovetail_offsetY, vTiltDovetail_offsetZ])
    rotate([-90, 0, 0])
    intersection(){
        union(){
            cylinder(d=vTiltDovetail_d1, h= vTolerance);
            translate([0, 0, vTolerance])
                cylinder(d1=vTiltDovetail_d1, d2=vTiltDovetail_d2, h=vTiltDovetail_h);
            };
        translate([-vTiltDovetail_d2/2, -vFrontPlate_height/2, 0])
            cube([vTiltDovetail_d2, vFrontPlate_height, vTiltDovetail_h+vTolerance]);
    };
    
    rotate([0, 0, 180])
        translate([vTiltDovetail_offsetX, vTiltDovetail_offsetY, vTiltDovetail_offsetZ])
        rotate([-90, 0, 0])
        intersection(){
            union(){
                cylinder(d=vTiltDovetail_d1, h= vTolerance);
                translate([0, 0, vTolerance])
                    cylinder(d1=vTiltDovetail_d1, d2=vTiltDovetail_d2, h=vTiltDovetail_h);
                };
            translate([-vTiltDovetail_d2/2, -vFrontPlate_height/2, 0])
                cube([vTiltDovetail_d2, vFrontPlate_height, vTiltDovetail_h+vTolerance]);
        };
    
    translate([vTiltLockBolt_offsetX, vTiltLockBolt_offsetY, vTiltLockBolt_offsetZ])
        rotate([-90, 0, 0])
            cylinder(d=vTiltLockBolt_d, h=vTiltLockBolt_h);
    translate([vTiltLockBolt_offsetX, -vTiltLockBolt_offsetY, vTiltLockBolt_offsetZ])
        rotate([90, 0, 0])
            cylinder(d=vTiltLockBolt_d, h=vTiltLockBolt_h);    
    
};



// lower bellows cutout (cube)
translate([vBellowsCutoutLower_offsetX, vBellowsCutoutLower_offsetY, vBellowsCutoutLower_offsetZ])
    cube([vBellowsCutoutLower_length, vBellowsCutoutLower_width, vBellowsCutoutLower_height]);    

// upper bellows cutout (cylinder with only 4 fragments)
translate([vBellowsCutoutUpper_offsetX, vBellowsCutoutUpper_offsetY, vBellowsCutoutUpper_offsetZ])
    rotate([0,0,45])
        cylinder(d1=vBellowsCutoutLower_d, d2=vBellowsCutoutUpper_d, h=vBellowsCutoutUpper_height, $fn=4);

// lensboard hole
cylinder(d=vLensBoardHole_d, h=vLensBoardHole_h);

// lensboard cutout
translate([vLensBoardCutout_offsetX, vLensBoardCutout_offsetY, vLensBoardCutout_offsetZ])
    cube([vLensBoardCutout_length, vLensBoardCutout_width, vLensBoardCutout_height]);        
// lensboard circular cutout
translate([0, 0, vLensBoardCircle_offsetZ])    
    cylinder(d=vLensBoardCircle_d, h=vLensBoardCircle_h);

// vertical screwholes
translate([vBellowsScrewHole_offsetX, -vBellowsScrewHole_offsetY, vBellowsScrewHole_offsetZ])
    rotate([0, 90, 0])
        cylinder(d=vBellowsScrewHole_d, h=vBellowsScrewHole_h);
translate([vBellowsScrewHole_offsetX, vBellowsScrewHole_offsetY, vBellowsScrewHole_offsetZ])
    rotate([0, 90, 0])
        cylinder(d=vBellowsScrewHole_d, h=vBellowsScrewHole_h);

// horizontal screwholes
translate([vBellowsScrewHole_offsetY, -vBellowsScrewHole_offsetX, vBellowsScrewHole_offsetZ])
    rotate([90, 0, 0])
        cylinder(d=vBellowsScrewHole_d, h=vBellowsScrewHole_h);
translate([-vBellowsScrewHole_offsetY, -vBellowsScrewHole_offsetX, vBellowsScrewHole_offsetZ])
    rotate([90, 0, 0])
        cylinder(d=vBellowsScrewHole_d, h=vBellowsScrewHole_h);

// sinkings for the bellows screws
// vertical
translate([vBellowsScrewHole_offsetX, vBellowsScrewHole_offsetY, vBellowsScrewHole_offsetZ])
    rotate([0, 90, 0])
        cylinder(d1=vBellowsScrewSinking_d1, h=vBellowsScrewSinking_h);
translate([vBellowsScrewHole_offsetX, -vBellowsScrewHole_offsetY, vBellowsScrewHole_offsetZ])
    rotate([0, 90, 0])
        cylinder(d1=vBellowsScrewSinking_d1, h=vBellowsScrewSinking_h);
translate([-vBellowsScrewHole_offsetX, vBellowsScrewHole_offsetY, vBellowsScrewHole_offsetZ])
    rotate([0, -90, 0])
        cylinder(d1=vBellowsScrewSinking_d1, h=vBellowsScrewSinking_h);
translate([-vBellowsScrewHole_offsetX, -vBellowsScrewHole_offsetY, vBellowsScrewHole_offsetZ])
    rotate([0, -90, 0])
        cylinder(d1=vBellowsScrewSinking_d1, h=vBellowsScrewSinking_h);

// horizontal
translate([vBellowsScrewHole_offsetY, -vBellowsScrewHole_offsetX, vBellowsScrewHole_offsetZ])
    rotate([90, 0, 0])
        cylinder(d1=vBellowsScrewSinking_d1, h=vBellowsScrewSinking_h);
translate([-vBellowsScrewHole_offsetY, -vBellowsScrewHole_offsetX, vBellowsScrewHole_offsetZ])
    rotate([90, 0, 0])
        cylinder(d1=vBellowsScrewSinking_d1, h=vBellowsScrewSinking_h);
translate([vBellowsScrewHole_offsetY, vBellowsScrewHole_offsetX, vBellowsScrewHole_offsetZ])
    rotate([-90, 0, 0])
        cylinder(d1=vBellowsScrewSinking_d1, h=vBellowsScrewSinking_h);
translate([-vBellowsScrewHole_offsetY, vBellowsScrewHole_offsetX, vBellowsScrewHole_offsetZ])
    rotate([-90, 0, 0])
        cylinder(d1=vBellowsScrewSinking_d1, h=vBellowsScrewSinking_h);

// axis holes
translate([vAxisHole_offsetX, vAxisHole_offsetY, vAxisHole_offsetZ])
    rotate([-90, 0, 0])
        cylinder(d=vAxisHole_d, h=vAxisHole_h);
        
translate([vAxisHole_offsetX, -vAxisHole_offsetY, vAxisHole_offsetZ])
    rotate([90, 0, 0])
        cylinder(d=vAxisHole_d, h=vAxisHole_h);

// tilt lock bolt holes
translate([vTiltLockBolt_offsetX, vTiltLockBolt_offsetY, vTiltLockBolt_offsetZ])
        rotate([-90, 0, 0])
            cylinder(d=vTiltLockBoltHole_d, h=vTiltLockBoltHole_h);
    translate([vTiltLockBolt_offsetX, -vTiltLockBolt_offsetY, vTiltLockBolt_offsetZ])
        rotate([90, 0, 0])
            cylinder(d=vTiltLockBoltHole_d, h=vTiltLockBoltHole_h);
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

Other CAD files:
STL_4x5/focus_wheel.stl
STL_5x7/ground_glass_clamp.stl
STL_4x5/front_standard_tilt_plate.stl
STL_5x7/slider.stl
SCAD/config_5x7.scad
SCAD/back_plate.scad
SCAD/bellows_back_frame.scad
SCAD/bellows_front_frame.scad
SCAD/body.scad
SCAD/focus_wheel.scad
SCAD/focusing_block.scad
SCAD/front_lid.scad
SCAD/front_lid_dovetail.scad
SCAD/front_standard.scad
SCAD/front_standard_tilt_plate.scad
SCAD/ground_glass_clamp.scad
SCAD/ground_glass_frame.scad
SCAD/lensboard_lower_clamp.scad
SCAD/lensboard_upper_clamp.scad
SCAD/locking_lever.scad
SCAD/locking_rail.scad
SCAD/modules.scad
SCAD/pulling_lever.scad
SCAD/pulling_lever_plate.scad
SCAD/rails.scad
SCAD/slider.scad
SCAD/tripod_plate.scad
STL_4x5/back_plate.stl
STL_4x5/front_lid_dovetail.stl
STL_4x5/front_standard.stl
STL_4x5/ground_glass_frame.stl
STL_4x5/lensboard_carrier.stl
STL_4x5/pulling_lever.stl
STL_4x5/slider.stl
STL_5x7/bellows_back_frame.stl
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

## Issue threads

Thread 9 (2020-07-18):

Request for documentation : exploded view & assembly guide

V-Roger, 2020-07-18:
# Request for documentation

Hi, **thanks for the great work**! I'm halfway through printing this, and the parts look great.

A greatly helpful addition to the already very detailed `READMEs` would be an exploded view of the camera and/or an assembly guide.

I'm pretty sure I could figure it out by myself as the design is rather smart, but mistakes are probable without the proper assembly instructions.

Thank you so much again, can't wait to expose some 4x5 !

edgarkech, 2020-07-20:
Hi Virgil,
thanks for your message.
Well, you know I used this project to switch from TinkerCAD to OpenSCAD. For the basic designing skills (single parts, but also making a design parametric) I suppose you can call this transition successful, but I didn't dive enough into it yet to create assemblies and/or exploded views.
Also, my intention was just a pure, personal project (besides the large format photography as "main" hobby"). Before releasing the design, I didn't spend (m)any thoughts on sourcing problems or documentation... 
Since then, my personal priorities have also shifted a bit, so I am currently quite short of time (and honestly motivation) for overall/extensive documentation work.
Nevertheless, I'll try to answer specific questions....

Edgar

V-Roger, 2020-07-20:
Hey Edgar!

Thanks for the reply, I get it it's a very time-consuming project :D

If I fall upon specific problems (as I'm not done printing yet I'm not sure what they might be), I'll be sure to ask you.

On a more open-source front, would you mind if I take it upon myself to create the exploded view and / or assembly guide ? Would be glad to help and give back to the project :)
If you're OK with it I'll shoot a PR this way when I'm done building mine.

Take care !

edgarkech, 2020-07-20:
> On a more open-source front, would you mind if I take it upon myself to create the exploded view and / or assembly guide ? Would be glad to help and give back to the project :)

... that's one reason why I switched over from thingiverse to github ;-)
Just let me know if you have any issues with permissions or other administrative stuff, so I can (hopefully) set it up.

Closed 2020-07-20.

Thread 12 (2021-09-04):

4x5 front_lid_dovetail STL seems short

drdpj, 2021-09-04:
**Describe the bug**
The STL is short (4 screw holes in length instead of 5), and the scad won't render as it is

**Expected behavior**
I think it should be rendering with 5 holes, equal to the length of the front lid

**Pictures**
If applicable, add pictures to help explain your problem.

**Additional context**
Updated 4x5 config attached, which I think fixes things (params taken from 5x7 config)? Another eye over it would be useful before I commit to a print!
[config_4x5.zip](https://github.com/edgarkech/scalable_field_camera/files/7110569/config_4x5.zip)

edgarkech, 2022-09-03:
sorry for the _very_ delayed response.
For the 4x5 version it does not matter if the dovetail is shorter than the lid - it won't add to stability/rigidity and it won't degrade functionality. So from my point of view this is not a real bug, especially if it is just a matter of configuration (as you found out).

Closed 2022-09-03.

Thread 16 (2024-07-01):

body.stl files doesn't fit with body.scad

un-named-man, 2024-07-01:
the body has the same border, but the window is slightly smaller in body.stl, thus bellows_back_frame (which doesn't have stl version in STL_4x5) exported from .sacd cannot fit in the body part printed with body.stl (4x5 version).

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

edgarkech, 2024-07-01:
Hi,
the above screenshot looks quite mixed up. The body should be almost square and without any "double" structures as shown above. I checked the available STL which looks exactly as expected (see https://github.com/edgarkech/scalable_field_camera/blob/master/STL_4x5/body.stl).
What I noticed within the SCAD files:
For creating a proper 4x5 STLs from the SCAD files, you have to check the baseconfig.scad file. This file has multilple "include" statements for the format specific config files. Please make sure to comment in the "include <config_4x5.scad>;" line and comment out the "include <config_5x7.scad>;". Then save and re-render the SCAD-files before exporting to STL.

edgarkech, 2024-10-02:
since there was no reaction to my suggestion, I am closing this issue.

Closed 2024-10-02.

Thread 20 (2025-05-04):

Aliexpress link to lead screw is linked to a T8, not T6

diamond-one, 2025-05-04:
**Describe the issue**
in the 4×5 parts list [ https://github.com/edgarkech/scalable_field_camera/tree/master/STL_4x5#45-parts-list[
You have a link to ali express for the lead screw, this is great, thanks, however I noticed that you are calling for a T6 in the parts list, and a T6 nut, so assume that the link you have provided for a T8 lead screw is incorrect

**Expected behavior**
The following link
https://www.aliexpress.com/item/1005007668102207.html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

Cheers

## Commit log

2020-02-24 Add files via upload
    initial commit for the first prototype parts
    [body.scad, front_lid.scad, front_standard.scad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]
2020-03-17 reworked some files
    reworked some files after first print approach:
    rails
    front lid
    body
    pulling lever
    pulling lever plate
    [body.scad, body_dovetail.scad, body_old.scad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]
2020-03-21 Add files via upload
    new versions for the first functional proptotype
    [back_plate.scad, body.scad, front_lid_dovetail.scad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]
2020-03-21 Delete body_old.scad
    replaced by newer version
    [body_old.scad]
2020-03-21 Delete body_dovetail.scad
    dovetails integrated into body.
    [body_dovetail.scad]
2020-03-22 Add files via upload
    reduced height due to collision with front standard when folding
    [focusing_block.scad]
2020-03-25 Add files via upload
    improved version after first print
    [focus_wheel.scad, focusing_block.scad, front_lid.scad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]
2020-03-26 Add files via upload
    initial STL files
    [back_plate.stl, body.stl, focus_wheel.stl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]
2020-03-28 adjusted measurements
    adjusted measurements because the tripod plate didn't fit onto various Arca Swiss compatible clamps
    [tripod_plate.stl]
2020-03-29 Add files via upload
    added a bit of tolerance to the hinges / hinge cutouts for better lid closing
    [body.stl]
2020-03-30 added front lid locking mechanism
    added to bolts to the rails and respective holes to the body to lock the front lid when closed.
    [body.stl, rails.stl]
2020-04-04 Add files via upload
    initial SCAD file upload with the first few files
    [baseconfig.scad, bellows_back_frame.scad, config_4x5.scad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]
2020-04-05 modified lens locking indents
    the lens locking indents were a tiny bit too close to the body, so that the slider wasn't completely on the rails with a 90mm lens.
    I moved the indents 5mm more from the body and changed also the distance between the indents from 20 to 25mm.
    [rails.scad]
2020-04-10 Add files via upload
    first set of real SCAD files
    [baseconfig.scad, body.scad, config_4x5.scad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]
2020-04-11 Add files via upload
    adjusted versions for version 1.0
    [focus_wheel.stl, focusing_block.stl, rails.stl]
2020-04-12 Add files via upload
    back plate addition and changes on config files
    [back_plate.scad, config_4x5.scad, config_5x7.scad]
2020-04-17 Add files via upload
    previous uploaded version was corrupted
    [lensboard_carrier.stl]
2020-04-22 Add files via upload
    ongoing transition to parametric files
    [baseconfig.scad, bellows_front_frame.scad, body.scad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]
2020-04-22 Add files via upload
    caution - files are for the first 5x7 mockup
    [bellows_back_frame.stl, bellows_front_frame.stl, body.stl]
2020-04-23 Add files via upload
    corrections
    [body.scad, config_5x7.scad]
2020-04-27 Add files via upload
    looks like some variables were missing in the config 4x5 file for the bellows front frame...
2020-05-10 Add files via upload
    new+updated versions
    [config_4x5.scad, config_5x7.scad, ground_glass_clamp.scad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]
2020-05-10 Add files via upload
    modified ground glass / cassette guides (slightly larger, so the ground glass frame will still be guided when a cassette is put into place)
    [back_plate.scad]
2020-06-05 Add files via upload
    added missing file for front standard
    [front_standard.scad]
2020-06-26 Add files via upload
    corrected version to fit focusing wheel and focusing block
    [front_lid.stl]
2020-07-28 📝 Add images of 3DFusion assembly of 4x5 models
2020-07-29 📝 Format main READMEs in markdown and add documentation README
2020-07-29 :bento: Replace bottom view with correct one (inverted tripod plate)
2020-11-27 fix for 4x5 version of lensboard carrier
    the lensboard carrier SCAD file had some issues with 4x5 because the final modifications/cleanup was made especially for 5x7 (additional cutout, slightly different proportions).
    please do not use any older config_4x5 in combination with the latest lensboard_carrier file.
    [config_4x5.scad, lensboard_carrier.scad]
2023-08-29 Update README
    added hints for bellows frames
    added hints for printing orientation for the front standart
2023-08-29 Update README.md
    added hints regarding front standard and bellows frames
2025-02-13 Update README
    directions for creating bellows frames
2025-02-13 Update config_4x5.scad
    added hint for bellows frames
    [config_4x5.scad]
2025-02-13 Update config_5x7.scad
    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
    [config_5x7.scad]
2025-02-13 Update baseconfig.scad
    set config_4x5.scad as default include
    [baseconfig.scad]
2025-08-19 Update README.md
    added some more hints for assembly
